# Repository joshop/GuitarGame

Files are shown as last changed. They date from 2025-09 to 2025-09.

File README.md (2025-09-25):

# GuitarGame
DELTARUNE's guitar rhythm game in electronic form using an STM32 microcontroller.
KiCAD EDA files are in the top level directory. `firmware/` contains the code.

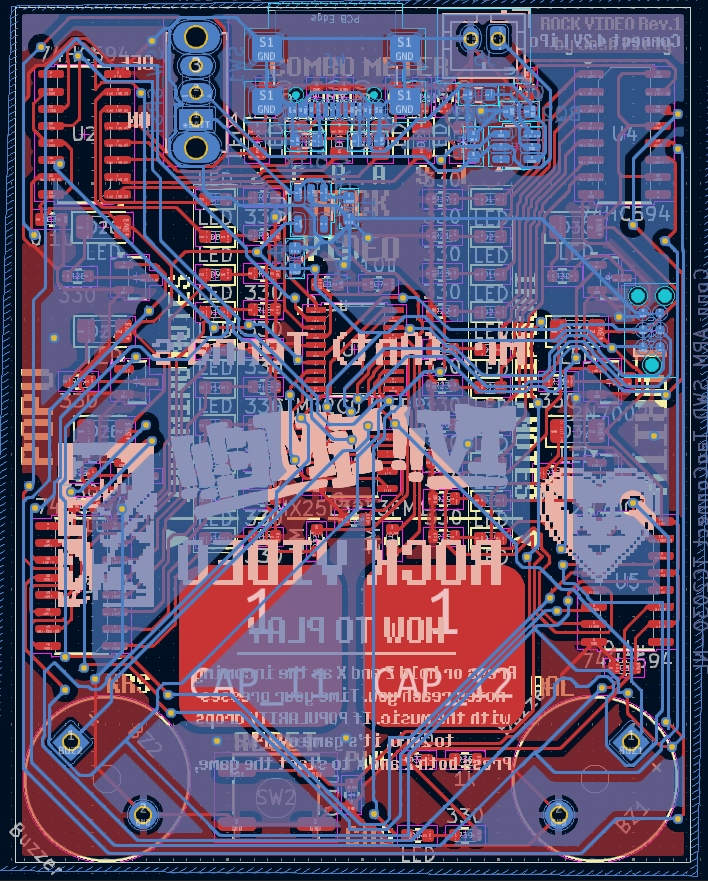
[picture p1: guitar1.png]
PCB Layout

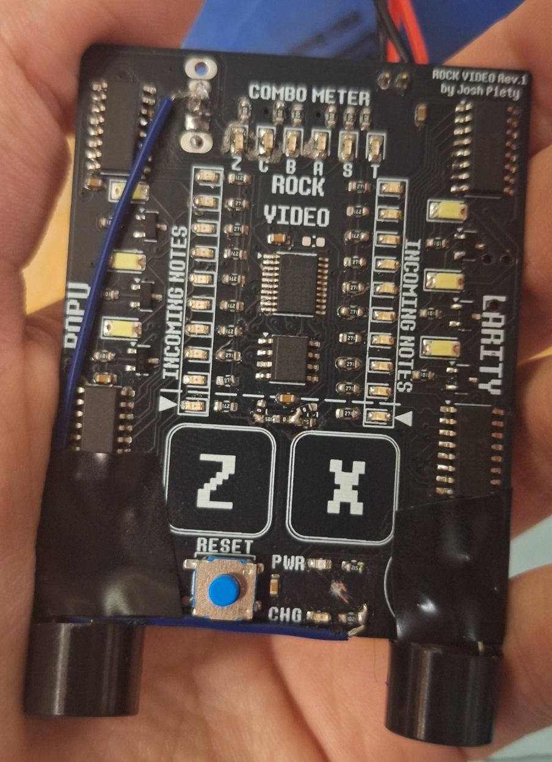
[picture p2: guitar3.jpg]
Front

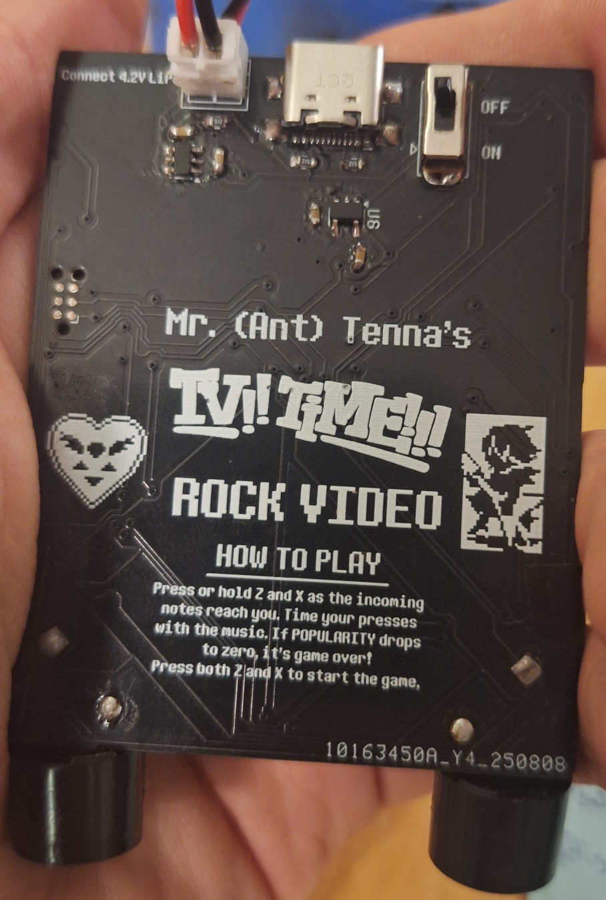
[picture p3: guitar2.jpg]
Back


## Design
- An STM32C071FBP6 microcontroller is at the core.
- Power is supplied from a 4.2V LiPo, managed using a BQ21040, or a USB-C port, via an LDO.
- Four 74HC594 shift registers are used to control the LEDs.
- Two piezo speakers are driven by the STM32 to produce audio.
- Two capacitive touch pads are driven through 1 megaohm resistors.

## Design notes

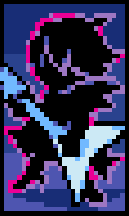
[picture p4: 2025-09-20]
intro.png

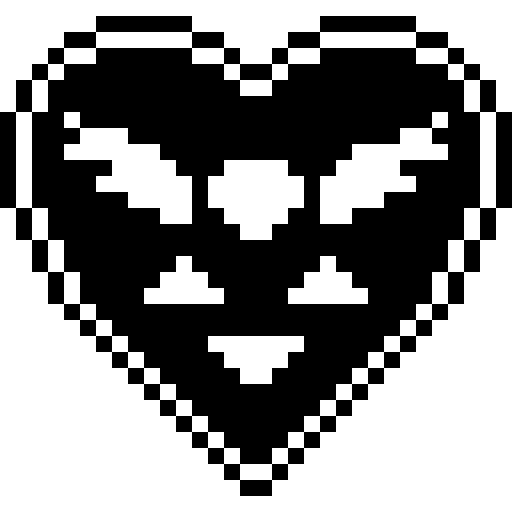
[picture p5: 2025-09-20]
deltarune.png

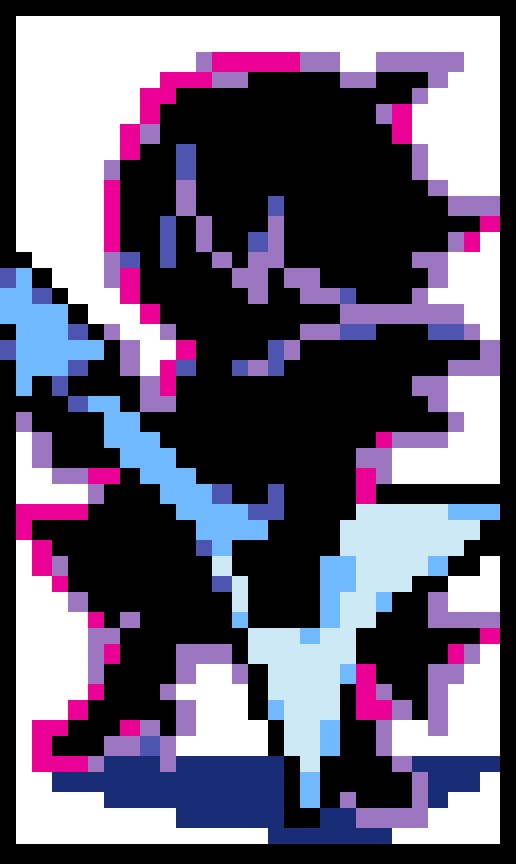
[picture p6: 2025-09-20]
intro2.png

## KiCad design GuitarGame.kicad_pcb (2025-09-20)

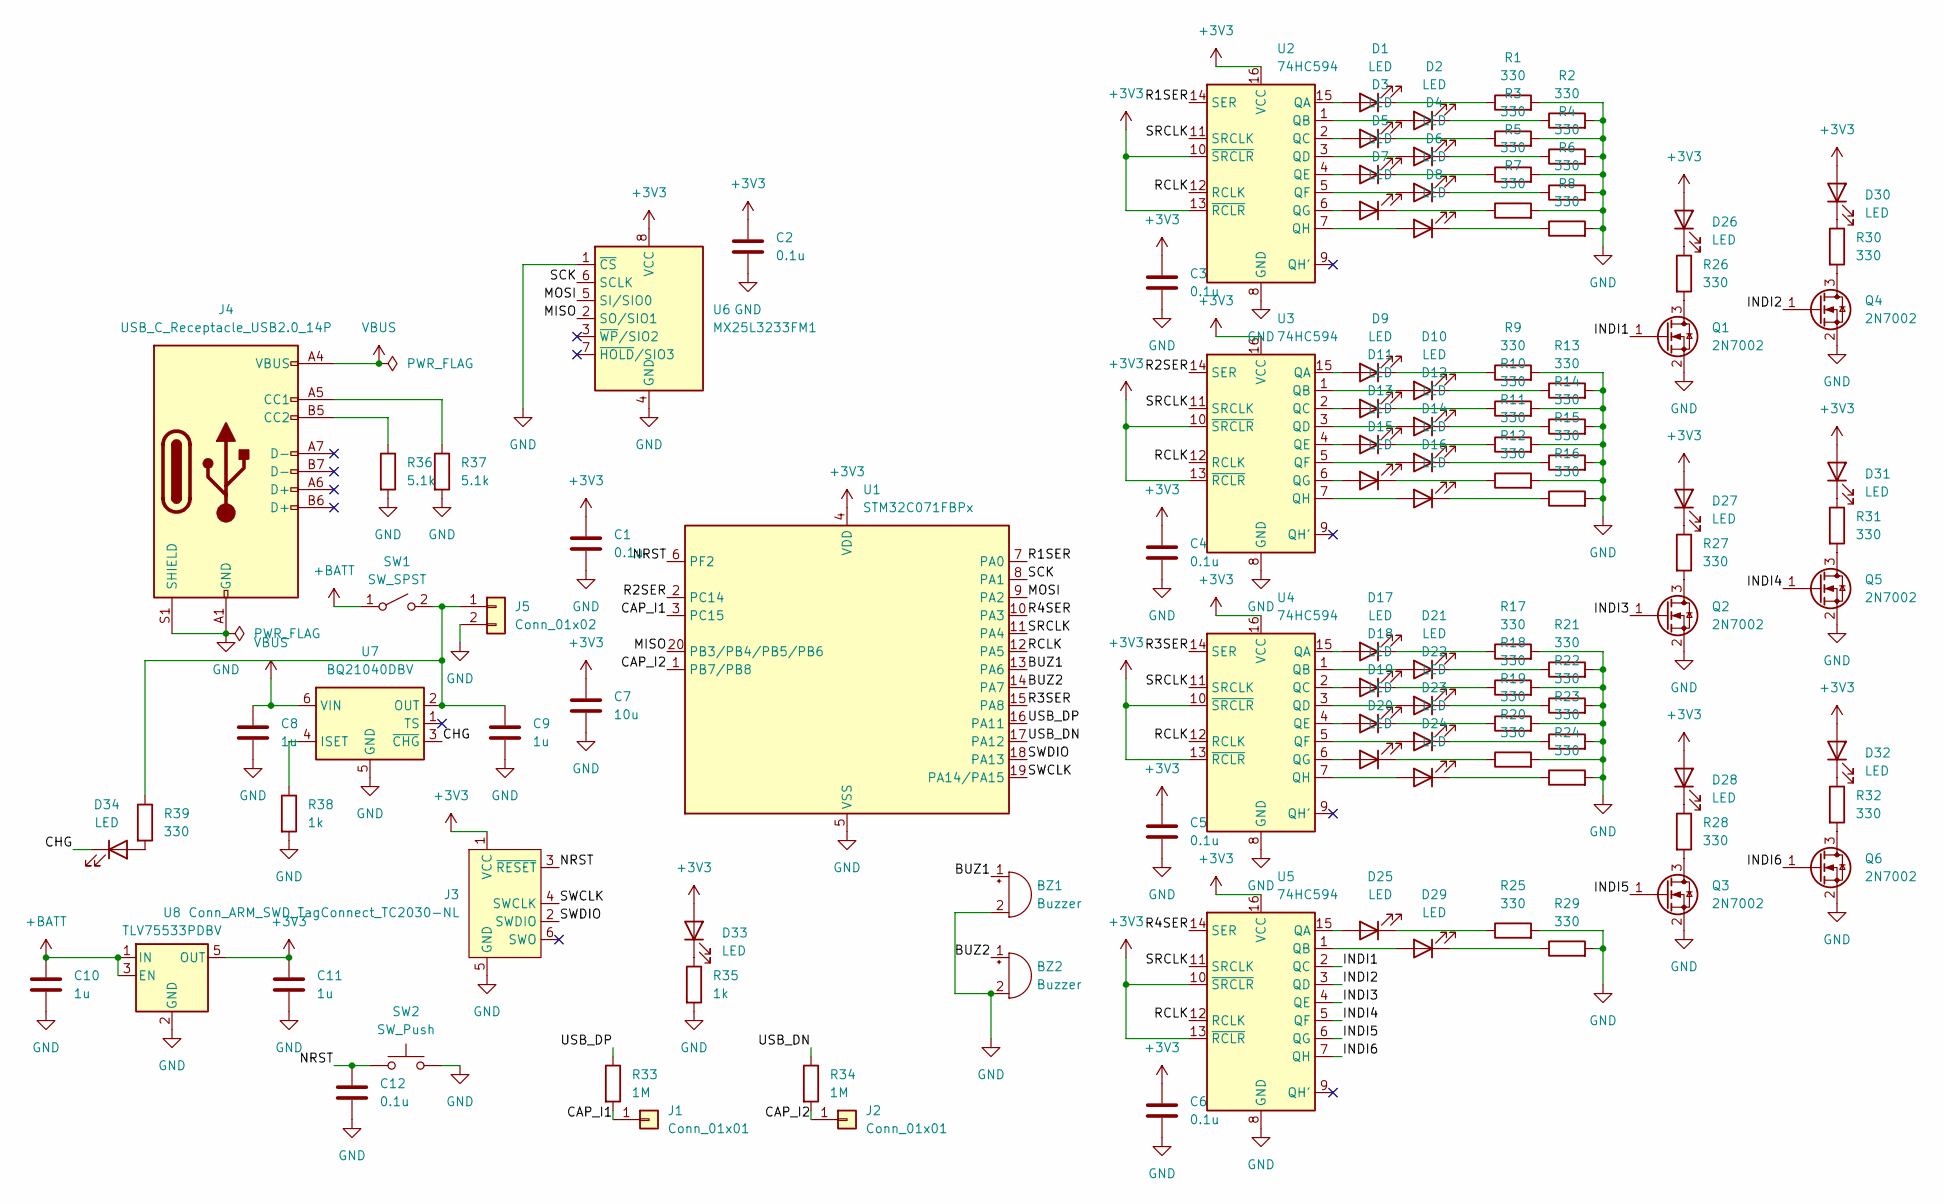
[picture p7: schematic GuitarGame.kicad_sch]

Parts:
BZ1, BZ2: Buzzer; Buzzer_12x9.5RM7.6
C1, C2, C3, C4, C5, C6, C12: 0.1u; C_0603_1608Metric
C7: 10u; C_0603_1608Metric
C8, C9, C10, C11: 1u; C_0603_1608Metric
D1, D2, D3, D4, D5, D6: LED; LED_0805_2012Metric
D7, D8, D9, D10, D11, D12, D13, D14, D15, D16, D17, D18, D19, D20, D21, D22, D23, D24, D25, D29: LED; LED_0603_1608Metric
D26, D27, D28, D30, D31, D32: LED; LED_1206_3216Metric
D33, D34: LED; C_0603_1608Metric
J1, J2: Conn_01x01; cap_pad
J3: Conn_ARM_SWD_TagConnect_TC2030-NL; Tag-Connect_TC2030-IDC-NL_2x03_P1.27mm_Vertical
J4: USB_C_Receptacle_USB2.0_14P; USB_C_Receptacle_GCT_USB4110
J5: Conn_01x02; JST_PH_B2B-PH-K_1x02_P2.00mm_Vertical
Q1, Q2, Q3, Q4, Q5, Q6: 2N7002; SOT-23
R1, R2, R3, R4, R5, R6, R7, R8, R9, R10, R11, R12, R13, R14, R15, R16, R17, R18, R19, R20, R21, R22, R23, R24, R25, R26, R27, R28, R29, R30, R31, R32, R39: 330; R_0603_1608Metric
R33, R34: 1M; R_0603_1608Metric
R35, R38: 1k; R_0603_1608Metric
R36, R37: 5.1k; R_0603_1608Metric
SW1: SW_SPST; SW_Slide_SPDT_Straight_CK_OS102011MS2Q
SW2: SW_Push; SW_Push_1P1T_NO_CK_KSC7xxJ
U1: STM32C071FBPx; TSSOP-20_4.4x6.5mm_P0.65mm
U2, U3, U4, U5: 74HC594; SOIC-16_3.9x9.9mm_P1.27mm
U6: MX25L3233FM1; JEITA_SOIC-8_3.9x4.9mm_P1.27mm
U7: BQ21040DBV; SOT-23-6
U8: TLV75533PDBV; SOT-23-5

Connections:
+BATT: C10.1, SW1.1 (A), U8.1 (IN), U8.3 (EN)
/BUZ1: BZ1.1 (+), U1.13 (PA6)
/BUZ2: BZ2.1 (+), U1.14 (PA7)
/CAP_I1: J1.1, R33.2, U1.3 (PC15)
/CAP_I2: J2.1, R34.2, U1.1 (PB7/PB8)
/CHG: D34.1 (K), U7.3 (~CHG)
/INDI1: Q1.1 (G), U5.2 (QC)
/INDI2: Q4.1 (G), U5.3 (QD)
/INDI3: Q2.1 (G), U5.4 (QE)
/INDI4: Q5.1 (G), U5.5 (QF)
/INDI5: Q3.1 (G), U5.6 (QG)
/INDI6: Q6.1 (G), U5.7 (QH)
/MISO: U1.20 (PB3/PB4/PB5/PB6), U6.2 (SO/SIO1)
/MOSI: U1.9 (PA2), U6.5 (SI/SIO0)
/NRST: C12.1, J3.3 (~RESET), SW2.1, U1.6 (PF2)
/R1SER: U1.7 (PA0), U2.14 (SER)
/R2SER: U1.2 (PC14), U3.14 (SER)
/R3SER: U1.15 (PA8), U4.14 (SER)
/R4SER: U1.10 (PA3), U5.14 (SER)
/RCLK: U1.12 (PA5), U2.12 (RCLK), U3.12 (RCLK), U4.12 (RCLK), U5.12 (RCLK)
/SCK: U1.8 (PA1), U6.6 (SCLK)
/SRCLK: U1.11 (PA4), U2.11 (SRCLK), U3.11 (SRCLK), U4.11 (SRCLK), U5.11 (SRCLK)
/SWCLK: J3.4 (SWCLK), U1.19 (PA14/PA15)
/SWDIO: J3.2 (SWDIO), U1.18 (PA13)
/USB_DN: R34.1, U1.17 (PA12)
/USB_DP: R33.1, U1.16 (PA11)
GND: BZ1.2 (-), BZ2.2 (-), C1.2, C2.2, C3.2, C4.2, C5.2, C6.2, C7.2, C8.2, C9.2, C10.2, C11.2, C12.2, J3.5 (GND), J4.A1 (GND), J4.A12 (GND), J4.B1 (GND), J4.B12 (GND), J4.S1 (SHIELD), J5.2, Q1.2 (S), Q2.2 (S), Q3.2 (S), Q4.2 (S), Q5.2 (S), Q6.2 (S), R1.2, R2.2, R3.2, R4.2, R5.2, R6.2, R7.2, R8.2, R9.2, R10.2, R11.2, R12.2, R13.2, R14.2, R15.2, R16.2, R17.2, R18.2, R19.2, R20.2, R21.2, R22.2, R23.2, R24.2, R25.2, R29.2, R35.2, R36.2, R37.2, R38.2, SW2.2, U1.5 (VSS), U2.8 (GND), U3.8 (GND), U4.8 (GND), U5.8 (GND), U6.1 (~CS), U6.4 (GND), U7.5 (GND), U8.2 (GND)
unnamed: D1.2 (A), U2.15 (QA)
unnamed: D1.1 (K), R1.1
unnamed: D2.2 (A), U2.1 (QB)
unnamed: D2.1 (K), R2.1
unnamed: D3.2 (A), U2.2 (QC)
unnamed: D3.1 (K), R3.1
unnamed: D4.2 (A), U2.3 (QD)
unnamed: D4.1 (K), R4.1
unnamed: D5.2 (A), U2.4 (QE)
unnamed: D5.1 (K), R5.1
unnamed: D6.2 (A), U2.5 (QF)
unnamed: D6.1 (K), R6.1
unnamed: D7.2 (A), U2.6 (QG)
unnamed: D7.1 (K), R7.1
unnamed: D8.2 (A), U2.7 (QH)
unnamed: D8.1 (K), R8.1
unnamed: D9.2 (A), U3.15 (QA)
unnamed: D9.1 (K), R9.1
unnamed: D10.2 (A), U3.1 (QB)
unnamed: D10.1 (K), R13.1
unnamed: D11.2 (A), U3.2 (QC)
unnamed: D11.1 (K), R10.1
unnamed: D12.2 (A), U3.3 (QD)
unnamed: D12.1 (K), R14.1
unnamed: D13.2 (A), U3.4 (QE)
unnamed: D13.1 (K), R11.1
unnamed: D14.2 (A), U3.5 (QF)
unnamed: D14.1 (K), R15.1
unnamed: D15.2 (A), U3.6 (QG)
unnamed: D15.1 (K), R12.1
unnamed: D16.2 (A), U3.7 (QH)
unnamed: D16.1 (K), R16.1
unnamed: D17.2 (A), U4.15 (QA)
unnamed: D17.1 (K), R17.1
unnamed: D18.2 (A), U4.2 (QC)
unnamed: D18.1 (K), R18.1
unnamed: D19.2 (A), U4.4 (QE)
unnamed: D19.1 (K), R19.1
unnamed: D20.2 (A), U4.6 (QG)
unnamed: D20.1 (K), R20.1
unnamed: D21.2 (A), U4.1 (QB)
unnamed: D21.1 (K), R21.1
unnamed: D22.2 (A), U4.3 (QD)
unnamed: D22.1 (K), R22.1
unnamed: D23.2 (A), U4.5 (QF)
unnamed: D23.1 (K), R23.1
unnamed: D24.2 (A), U4.7 (QH)
unnamed: D24.1 (K), R24.1
unnamed: D25.2 (A), U5.15 (QA)
unnamed: D25.1 (K), R25.1
unnamed: D26.1 (K), R26.1
unnamed: D27.1 (K), R27.1
unnamed: D28.1 (K), R28.1
unnamed: D29.2 (A), U5.1 (QB)
unnamed: D29.1 (K), R29.1
unnamed: D30.1 (K), R30.1
unnamed: D31.1 (K), R31.1
unnamed: D32.1 (K), R32.1
unnamed: D33.1 (K), R35.1
unnamed: D34.2 (A), R39.2
unnamed: J4.A5 (CC1), R37.1
unnamed: J4.B5 (CC2), R36.1
unnamed: Q1.3 (D), R26.2
unnamed: Q2.3 (D), R27.2
unnamed: Q3.3 (D), R28.2
unnamed: Q4.3 (D), R30.2
unnamed: Q5.3 (D), R31.2
unnamed: Q6.3 (D), R32.2
unnamed: R38.1, U7.4 (ISET)
VBUS: C8.1, J4.A4 (VBUS), J4.A9 (VBUS), J4.B4 (VBUS), J4.B9 (VBUS), U7.6 (VIN)

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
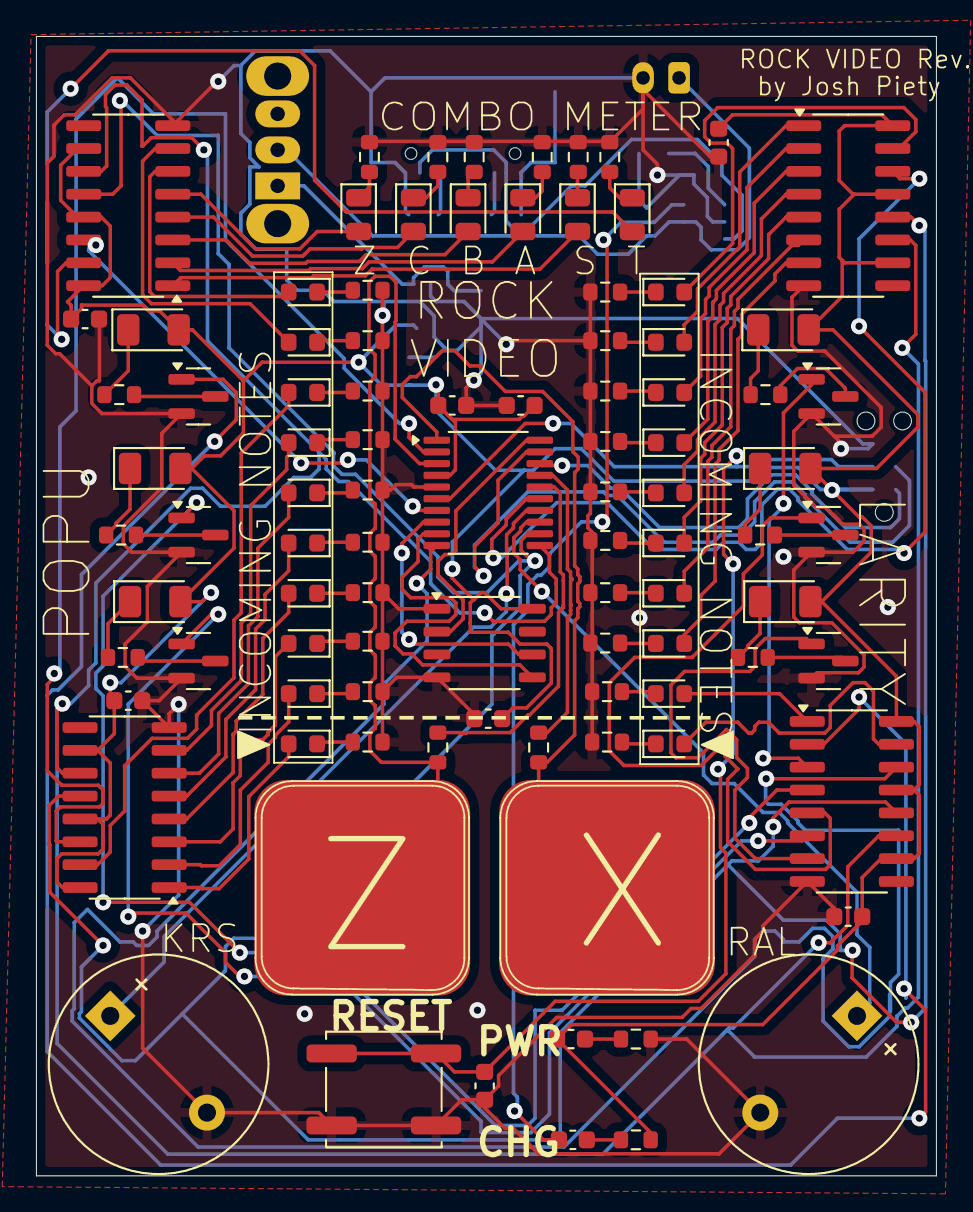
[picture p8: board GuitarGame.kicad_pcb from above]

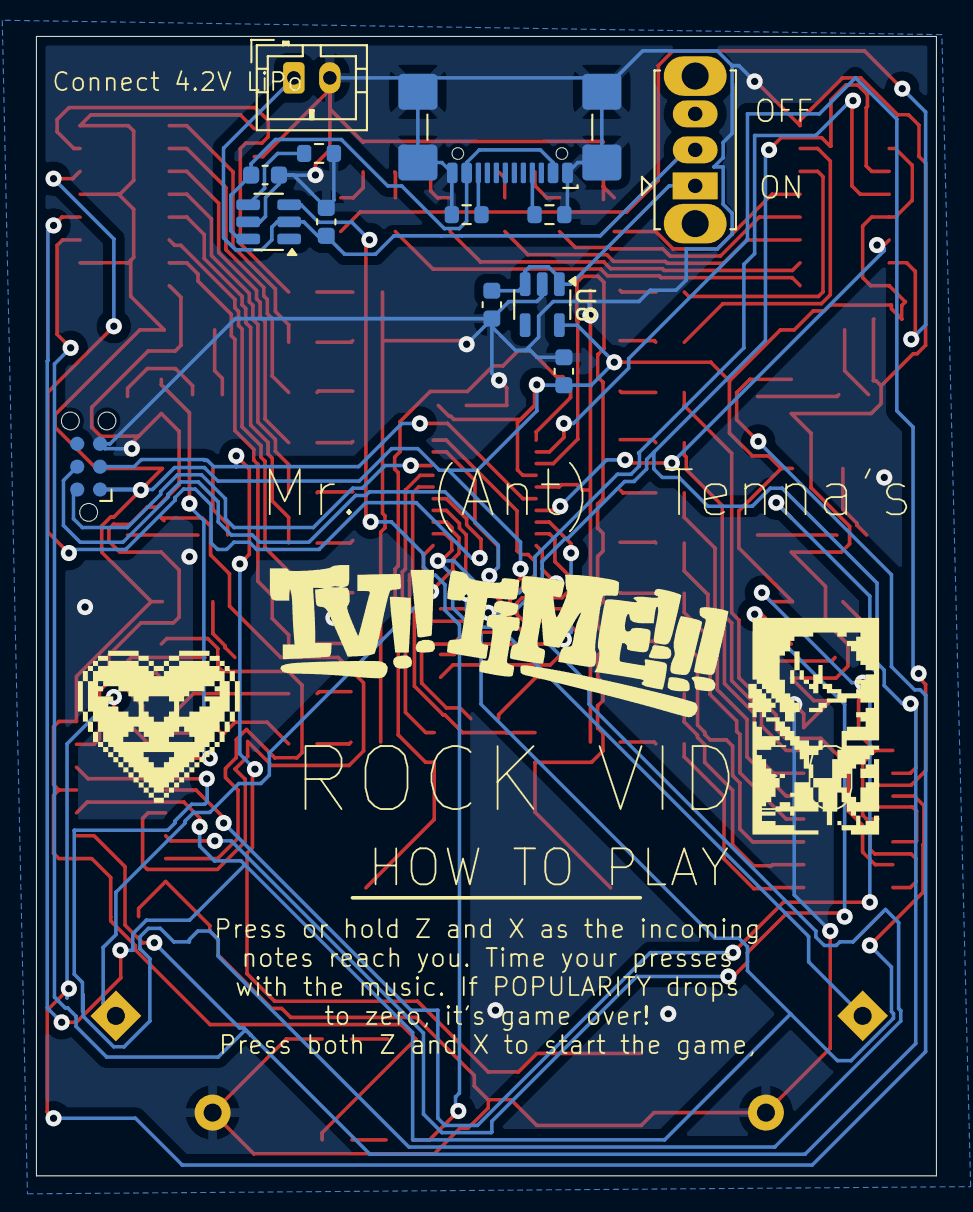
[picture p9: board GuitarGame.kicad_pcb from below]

Board: 2 copper layers, 50.0 x 63.3 mm, 108 parts (13 on the bottom side), 99 nets.

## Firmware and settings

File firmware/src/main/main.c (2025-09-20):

#include "cap_touch.h"
#include "hardware.h"
#include "its_tv_time.h"
#include "music.h"
#include "shift_register.h"
#include "stm32c0xx_hal.h"
#include "stm32c0xx_hal_tim.h"
#include <math.h>
#include <stdlib.h>
#include <string.h>

uint32_t pwmbits[3];
uint8_t which_period = 0;
volatile bool tick_flag;

const Note *all_notes;
uint32_t num_notes;
uint32_t cur_idx = 0;

const int32_t DISPLAY_DIVIDER = 4;
const int32_t DISPLAY_LEN = 9;

const uint8_t LEFT_DISP_IDXS[] = {25, 21, 17, 13, 9, 5, 1, 29, 28, 0};
const uint8_t RIGHT_DISP_IDXS[] = {27, 23, 30, 2, 6, 10, 14, 18, 22, 26};
const uint8_t COMBO_DISP_IDXS[] = {4, 8, 12, 16, 20, 24};
const uint8_t POPU_DISP_IDXS[] = {3, 11, 19, 31, 7, 15};

void place_aa_note(int32_t pos, const uint8_t *base, uint8_t bright) {
  uint8_t sub = pos % DISPLAY_DIVIDER;
  uint8_t start = pos / DISPLAY_DIVIDER;
  switch (sub) {
  case 0:
    if (start != 0)
      pwm_buffer[base[start - 1]] += bright / 2;
    pwm_buffer[base[start]] += bright / 2;
    break;
  case 1:
    if (start != 0)
      pwm_buffer[base[start - 1]] += bright / 4;
    pwm_buffer[base[start]] += 3 * bright / 4;
    break;
  case 2:
    pwm_buffer[base[start]] += bright;
    break;
  case 3:
    if (start != DISPLAY_LEN - 1)
      pwm_buffer[base[start + 1]] += bright / 4;
    pwm_buffer[base[start]] += 3 * bright / 4;
    break;
  default:
  }
}

uint8_t *notes_clicked;
void render_notes() {
  for (uint32_t i = 0; i < num_notes; i++) {

    int32_t dist = all_notes[i].start - cur_idx;
    int32_t dist2 = all_notes[i].end - cur_idx;
    int32_t pos1 = dist;
    int32_t pos2 = dist2;
    if (all_notes[i].end == 0) {
      if (notes_clicked[i])
        continue;
      pos2 = pos1;
    }
    pos2++;
    for (int32_t pos = pos1; pos < pos2; pos++) {
      if (pos < 0 || pos >= DISPLAY_LEN * DISPLAY_DIVIDER)
        continue;
      uint8_t chan = all_notes[i].channel;
      uint8_t base = pos == pos1 ? 100 : 2;
      /*if (chan == 0) {
        pwm_buffer[LEFT_DISP_IDXS[pos]] = base;
      } else {
        pwm_buffer[RIGHT_DISP_IDXS[pos]] = base;
      }*/
      if (chan == 0) {
        place_aa_note(pos, LEFT_DISP_IDXS + 1, base);
      } else {
        place_aa_note(pos, RIGHT_DISP_IDXS + 1, base);
      }
    }
  }
}

uint32_t noteleft1, noteleft2;
uint32_t death_time = 0;
void play_deathsound() {
  float frequency_hz = 200;
  float base = 723.422;
  uint32_t prescaler;
  for (prescaler = 0; prescaler < 65536; prescaler++) {
    if (frequency_hz > base / (prescaler + 1))
      break;
  }
  uint16_t arr = (48000000.0f / ((prescaler + 1) * frequency_hz)) - 1;
  TIM_HandleTypeDef *tim_chan = &htim3;
  tim_chan->Init.Prescaler = prescaler;
  tim_chan->Init.CounterMode = TIM_COUNTERMODE_UP;
  tim_chan->Init.Period = arr;
  tim_chan->Init.ClockDivision = TIM_CLOCKDIVISION_DIV1;
  tim_chan->Init.AutoReloadPreload = TIM_AUTORELOAD_PRELOAD_DISABLE;
  if (HAL_TIM_PWM_Init(tim_chan) != HAL_OK) {
    Error_Handler();
  }
  TIM_OC_InitTypeDef sConfigOC = {0};
  sConfigOC.OCMode = TIM_OCMODE_PWM1;
  // sConfigOC.Pulse = (channel == 1 ? 3 : 1) * arr / 4;
  sConfigOC.Pulse = 1400;
  sConfigOC.OCPolarity = TIM_OCPOLARITY_HIGH;
  sConfigOC.OCFastMode = TIM_OCFAST_DISABLE;
  if (HAL_TIM_PWM_ConfigChannel(tim_chan, &sConfigOC, TIM_CHANNEL_1) !=
      HAL_OK) {
    Error_Handler();
  }
}
void play_note(float frequency_hz, uint8_t channel, uint32_t ticks) {
  if (channel == 0 && death_time > 5) {
    HAL_TIM_PWM_Stop(&htim3, TIM_CHANNEL_1);
    HAL_TIM_PWM_DeInit(&htim3);
    noteleft1 = ticks;
    return;
  }
  if (frequency_hz < 10) {
    if (channel == 0) {
      HAL_TIM_PWM_Stop(&htim3, TIM_CHANNEL_1);
      HAL_TIM_PWM_DeInit(&htim3);
    } else {
      HAL_TIM_PWM_Stop(&htim17, TIM_CHANNEL_1);
      HAL_TIM_PWM_DeInit(&htim17);
    }
  } else {
    float base = 723.422;
    uint32_t prescaler;
    for (prescaler = 0; prescaler < 65536; prescaler++) {
      if (frequency_hz > base / (prescaler + 1))
        break;
    }
    uint16_t arr = (48000000.0f / ((prescaler + 1) * frequency_hz)) - 1;
    TIM_HandleTypeDef *tim_chan = channel == 0 ? &htim3 : &htim17;
    tim_chan->Init.Prescaler = prescaler;
    tim_chan->Init.CounterMode = TIM_COUNTERMODE_UP;
    tim_chan->Init.Period = arr;
    tim_chan->Init.ClockDivision = TIM_CLOCKDIVISION_DIV1;
    tim_chan->Init.AutoReloadPreload = TIM_AUTORELOAD_PRELOAD_DISABLE;
    if (HAL_TIM_PWM_Init(tim_chan) != HAL_OK) {
      Error_Handler();
    }
    TIM_OC_InitTypeDef sConfigOC = {0};
    sConfigOC.OCMode = TIM_OCMODE_PWM1;
    // sConfigOC.Pulse = (channel == 1 ? 3 : 1) * arr / 4;
    sConfigOC.Pulse = channel == 1 ? (frequency_hz < 200 ? 400 : 800)
                                   : (frequency_hz > base ? 2800 : 1400);
    sConfigOC.OCPolarity = TIM_OCPOLARITY_HIGH;
    sConfigOC.OCFastMode = TIM_OCFAST_DISABLE;
    if (HAL_TIM_PWM_ConfigChannel(tim_chan, &sConfigOC, TIM_CHANNEL_1) !=
        HAL_OK) {
      Error_Handler();
    }
  }
  if (channel == 0)
    noteleft1 = ticks;
  else
    noteleft2 = ticks;
  if (frequency_hz > 10) {
    if (noteleft1)
      HAL_TIM_PWM_Start(&htim3, TIM_CHANNEL_1);
    if (noteleft2)
      HAL_TIM_PWM_Start(&htim17, TIM_CHANNEL_1);
  }
}
uint8_t flash_cycle = 0;
const uint8_t TIMING_RANGE_EARLY = 15;
const uint8_t TIMING_RANGE_LATE = 8;
int main(void) {
  HAL_Init();
  SystemClock_Config();

  MX_GPIO_Init();
  MX_SPI1_Init();
  MX_TIM3_Init();
  MX_TIM2_Init();
  // MX_TIM1_Init();
  MX_TIM14_Init();
  MX_TIM16_Init();
  MX_TIM17_Init();

  HAL_Delay(100);
  captouch_init();
  shiftreg_init();
  bool touch1, touch2;
  bool new_touch1, new_touch2;
  new_touch1 = false;
  touch1 = false;
  new_touch2 = false;
  touch2 = false;
  HAL_TIM_Base_Start_IT(&htim14);
  HAL_TIM_Base_Start_IT(&htim16);
start_again:
  //  HAL_TIM_Base_Start_IT(&htim1);
  memset((uint8_t *)pwm_buffer, 1, 32);
  pwm_threshold = 0;
  // uint8_t x = 0;
  all_notes = tvtime_beats;
  num_notes = 501;
  notes_clicked = calloc(num_notes, 1);
  // play_note(880, 0, 60);
  // play_note(500, 1, 60);
  int disable1 = 0;
  int disable2 = 0;
  noteleft1 = disable1 ? 0 : 2.5 * 60;
  noteleft2 = disable2 ? 0 : 2.5 * 60;
  flash_cycle = 0;
  const AudioNote *cur_ch0 = tvtime_left;
  const AudioNote *cur_ch1 = tvtime_right;
  uint8_t lives = 18;
  uint32_t miss_cooldown = 0;
  uint8_t press_flash[2] = {0, 0};
  while (1) {
    if (lives == 0) {
      play_deathsound();
      HAL_TIM_PWM_Stop(&htim17, TIM_CHANNEL_1);
      HAL_TIM_PWM_DeInit(&htim17);
      HAL_Delay(700);
      HAL_TIM_PWM_Stop(&htim3, TIM_CHANNEL_1);
      HAL_TIM_PWM_DeInit(&htim3);
      cur_idx = 0;
      goto start_again;
    }
    new_touch1 = touch1;
    new_touch2 = touch2;
    read_touch_state(&touch1, &touch2);
    new_touch1 = touch1 && !new_touch1;
    new_touch2 = touch2 && !new_touch2;
    memset((uint8_t *)pwm_buffer, 0, 32);
    if (death_time > 10) {
      for (uint8_t i = 0; i < 6; i++) {
        pwm_buffer[COMBO_DISP_IDXS[i]] = 12 * (death_time - 10);
      }
    } else {
      for (uint8_t i = 0; i < 1 + (cur_idx * 6 / 10000); i++) {
        pwm_buffer[COMBO_DISP_IDXS[i]] = 100;
      }
    }
    // new_touch1 |= new_touch2;
    // new_touch2 |= new_touch1;
    if ((new_touch1 || new_touch2) && !miss_cooldown) {
      if (new_touch1)
        press_flash[0] = 7;
      if (new_touch2)
        press_flash[1] = 7;
      uint8_t all_miss = 1;
      for (uint32_t i = 0; i < num_notes; i++) {
        if (notes_clicked[i])
          continue;
        if (all_notes[i].channel && !new_touch2)
          continue;
        if (!all_notes[i].channel && !new_touch1)
          continue;
        int32_t dist = all_notes[i].start - cur_idx;
        if (!(dist > TIMING_RANGE_EARLY || dist < -TIMING_RANGE_LATE)) {
          all_miss = 0;
          notes_clicked[i] = 1;
          break;
        }
      }
      if (all_miss) {
        miss_cooldown = 11;
      }
    }
    if (press_flash[0]) {
      for (uint8_t i = 0; i < TIMING_RANGE_EARLY / DISPLAY_DIVIDER + 1; i++) {
        pwm_buffer[LEFT_DISP_IDXS[i]] += 10 * press_flash[0];
      }
      press_flash[0]--;
    }
    if (press_flash[1]) {
      for (uint8_t i = 0; i < TIMING_RANGE_EARLY / DISPLAY_DIVIDER + 1; i++) {
        pwm_buffer[RIGHT_DISP_IDXS[i]] += 10 * press_flash[1];
      }
      press_flash[1]--;
    }
    if (miss_cooldown)
      miss_cooldown--;
    if (death_time == 0) {
      for (uint32_t i = 0; i < num_notes; i++) {
        if (notes_clicked[i])
          continue;
        int32_t dist = all_notes[i].start - cur_idx;
        if (dist == -TIMING_RANGE_LATE - 1) {
          if (lives)
            lives--;
          death_time = 20;
          play_deathsound();
          // HAL_TIM_PWM_Stop(&htim3, TIM_CHANNEL_1);
          // HAL_TIM_PWM_DeInit(&htim3);
        }
      }
    }
    if (death_time)
      death_time--;
    render_notes();
    //  x++;
    //  HAL_Delay(5000);
    if (!disable1) {
      if (noteleft1)
        noteleft1--;
      if (!noteleft1) {
        play_note(cur_ch0->frequency, 0, cur_ch0->end);
        cur_ch0++;
      }
    }
    if (!disable2) {
      if (noteleft2)
        noteleft2--;
      if (!noteleft2) {
        play_note(cur_ch1->frequency, 1, cur_ch1->end);
        cur_ch1++;
      }
    }
    flash_cycle++;
    pwm_buffer[POPU_DISP_IDXS[0]] = lives > 6 ? 18 : lives;
    pwm_buffer[POPU_DISP_IDXS[3]] = lives > 6 ? 18 : lives;
    pwm_buffer[POPU_DISP_IDXS[1]] =
        lives > 12 ? 18 : (lives < 6 ? 0 : (lives - 6));
    pwm_buffer[POPU_DISP_IDXS[4]] =
        lives > 12 ? 18 : (lives < 6 ? 0 : (lives - 6));
    pwm_buffer[POPU_DISP_IDXS[2]] = lives < 12 ? 0 : (lives - 12);
    pwm_buffer[POPU_DISP_IDXS[5]] = lives < 12 ? 0 : (lives - 12);
    /*if (flash_cycle <= 18) {
      for (uint8_t i = 0; i < 6; i++) {
        pwm_buffer[POPU_DISP_IDXS[i]] = 0;
      }
    }*/

    if (flash_cycle == 24)
      flash_cycle = 0;
    /*if (noteleft2)
      noteleft2--;
    else
      HAL_TIM_PWM_Stop(&htim17, TIM_CHANNEL_1);*/
    tick_flag = true;
    while (tick_flag)
      ;
    cur_idx++;
  }
}
const int8_t dpcm_lut[] = {-6, -1, 1, 6};
void HAL_TIM_PeriodElapsedCallback(TIM_HandleTypeDef *htim) {
  if (htim == &htim16) {
    pwm_threshold++;
    shift_all();
  } else if (htim == &htim14) {
    tick_flag = false;
  } else if (htim == &htim1) {
  }
}

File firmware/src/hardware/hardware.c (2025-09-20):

/* USER CODE BEGIN Header */

#include "hardware.h"
#include "stm32c0xx_hal.h"
#include "stm32c0xx_hal_rcc_ex.h"

SPI_HandleTypeDef hspi1;

TIM_HandleTypeDef htim16;
TIM_HandleTypeDef htim14;
TIM_HandleTypeDef htim1;
TIM_HandleTypeDef htim2;
TIM_HandleTypeDef htim3;
TIM_HandleTypeDef htim17;
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
